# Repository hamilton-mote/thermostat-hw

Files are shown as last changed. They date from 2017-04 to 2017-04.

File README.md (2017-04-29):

# Hamilton open-source thermostat

The Hamilton thermostat is an open-source single stage thermostat built around the [Hamilton](https://github.com/hamilton-mote/hw) and [Nucleum](https://github.com/lab11/nucleum) motes. The core motivation of the project is to integrate the hardware necessary to turn these low-cost and low-power motes into an energy efficient and feature-rich thermostat.

The Hamilton thermostat can control a standard single stage heating and/or cooling system with a circular fan (R/Rh/Rc, W, Y, and G wires). The design features a temperature sensor (AT30TS74), humidity/temperature sensor (HDC1080), PIR sensor (EKMB1101111), real-time clock (MCP7940N), and 1Mbit EEPROM (AT24CM01). Wireless communication is achieved via the 802.15.4 radio (built into the SAMR21 of the Hamilton mote) or the Bluetooth Low Energy (BLE) radio (built into the NRF51822 of the Nucleum mote). The thermostat can be powered by 3 AA batteries or by 24VAC power (requires a C wire). The design also includes a simple user interface with 4 buttons and LED-based temperature and setting indication. The user interface can easily be replaced with a custom board by connecting to the main thermostat board via pinouts for the I2C bus, power (+3V3/GND), 2 analog pins, and 4 digital pins.

### Parts Overview

* AT30TS74 (I2C Address 1001000): The AT30TS74 temperature sensor has a configurable resolution of 9 to 12 bits and a typical accuracy of +/- 1 degree Celsius.
* HDC1080 (I2C Address 1000000): The HDC1080 humidity and temperature sensor has a configurable resolution of 8, 11, or 14 bits for humidity and 11 or 14 bit for temperature. The typical accuracy for humidity and temperature is +/- 2% and +/- 0.2 degree Celsius, respectively.
* MCP7940N (I2C Address 1101111): The MCP7940N is a real-time clock/calendar with SRAM.
* AT24CM02 (I2C Address 10100###): The AT24CM02 provides 2-Mbits (256-Kbytes) of Serial EEPROM. (Note: The original version of the Hamilton thermostat included AT24CM01 chips)
* PCA9557 (I2C Address 0011000): The PCA9557 is an 8 channel I/O parallel port expander. The expander is used to control the 3 latching relays (EE2-3TNUH-L) which actuate the heating system, cooling system, and circular fan.
* TLC59116 (I2C Addresses 1100001, 1100011, and 1100111): The TLC59116 is a 16 channel constant-current LED sink driver with 256-step (8-bit) linear programmable brightness. The Hamilton thermostat interface board includes 3 TLC59116 chips.
* EKMB1101111: The EKMB1101111 is a fully integrated PIR motion sensor with 1µA low current consumption. The output of the PIR sensor is connected to pin PA06 of the SAMR21 chip and P05/AIN6 of the NRF51822 chip.

### Communication

Communication between the SAMR21 chip or the NRF51822 chip and the other components of the Hamilton thermostat is primarily achieved via the shared I2C bus. The SAMR21 chip is connected to the bus with pin PA16 as SDA and PA17 as SCL and the NRF51822 chip is connected with pin P07 as SDA and P01 as SCL. The I2C addresses of the components are noted in the list above.

Communication between the SAMR21 chip and the NRF51822 chip is achieved over an SPI link. The SAMR21 chip is design to use SERCOM2 with PA08/PAD[0] as MOSI, PA09/PAD[1] as MISO,
PA15/PAD[3] as SCK, and PA14/PAD[2] as chip select.  The NRF51822 chip provides flexibility in the assignment of SPI pins and is designed to use P30 as MOSI, P29 as MISO, P00 as SCK, and P28 as chip select.

Additionally, the SAMR21 and NRF51822 chips are connected by several additional traces.
* A6 (the PIR sensor output) to SAMR21 pin PA06 and NRF51822 pin P05/AIN6.
* A7 to SAMR21 pin PA07 and NRF51822 pin P06/AIN7.
* D18 to SAMR21 pin PA18 and NRF51822 pin P18.
* D19 to SAMR21 pin PA19 and NRF51822 pin P19. There is also an LED connected to D19.
* D24 to SAMR21 pin PA24 and NRF51822 pin P25.
* D25 to SAMR21 pin PA25 and NRF51822 pin P25.
If necessary, these traces can be physically cut on the bottom on the Hamilton thermostat main board to sever the connections to the NRF51822 chip.

Lastly, the Hamilton thermostat is capable of wireless communication via the 802.15.4 radio (built into the SAMR21 chip) and the BLE radio (built into the NRF51822 chip).

### Relays

The Hamilton thermostat main board includes 3 EE2-3TNUH-L dual-coil latching signal relays for actuating a heating system (W wire), cooling system (Y wire), and circular fan (G wire).  Each relay is rated for a coil voltage of 3VDC, a contact current of 2A, and a switching voltage of up to 250VAC. Because the EE2-3TNUH-L is a latching relay, it maintains the contact position indefinitely without requiring a current to be applied. Thus, each relay contains 2 coils (1 for setting and 1 for releasing) and a current pulse is applied to either coil to change the contact position. Note that applying a current to one of the coils over a long period of time will damage the relay.

Each relay is connected to either the W wire (heat), Y wire (cooling), or G wire (fan). Setting a relay will connect the respective wire to the R/Rh/Rc wire and releasing the relay will sever the connection. The relays are controlled via the PCA9557 8 channel I/O expander. The W relay is connected to IO0 for setting and IO1 for releasing, the Y relay to IO2 for setting and IO3 for releasing, and the G relay to IO4 for setting and IO5 for releasing.

Lastly, the Hamilton thermostat is capable of simultaneously connecting the G wire (fan) when the W relay or Y relay is set. Adding the R18 jumper will cause the W relay to connect both the W and G wires to R when the relay is set and adding the R17 jumper will cause the Y relay to connect the Y and G relays to R.

### Power

The Hamilton thermostat can be power by battery and/or 24VAC power (if a C wire is available). The Hamilton thermostat main board includes a 3 AA battery holder and a AP2210 3.3VDC 300mA LDO regulator. If necessary, regulator can be bypassed by adding the R1 jumper.

If a C wire is available, the thermostat can operate on 24VAC power. For AC/DC conversion, the main board includes a full wave bridge rectifier and an OKI-78SR 36VDC to 3.3VDC 1.5A buck converter. The thermostat is designed to allow for operation on 24VAC power with battery backup.

### User Interface

The Hamilton thermostat has a simple and intuitive user interface for communicating the current temperature measurement and set point and for enabling a user to perform basic operations like setting the mode (heating, cooling, off) and adjusting the set point. The interface board includes four buttons: one for setting the mode, two for adjusting the temperature set point, and one for setting a temporary temperature hold.

The board also includes 40 LEDs for denoting the thermostats settings. To communicate the current temperature measurement and set point, 32 of the LEDs are arranged in an arc around the center of the board (16 for the measurement and 16 for the set point). The LEDs are controlled via three TLC59116 16 channel LED sink drivers.

The interface board is connected to the main thermostat board via pinouts for the I2C bus (SDA and SCL), power (+3.3VDC and GND), analog pins A6 and A7, and digital pins D18, D19, D24, and D25.

### Transient Voltage Suppression (TVS)

To protect the thermostat components from voltage spikes and electrostatic discharge (ESD), the Hamilton thermostat main and interface boards include several transient-voltage-suppression diodes.

On the main board:
* Diode D2 protects the 24VDC output of the diode rectifier and the voltage input of the buck converter.
* Diode D15 protects the batteries and the voltage input of the LDO regulator.
* Diode D16 protects the 3.3V line.
* Integrated diodes U8 (IP4220CZ6) protects the I2C lines.

On the interface board:
* Diodes D41, D42, D43, and D44 protect the output of each button on the interface board.
* Diode D45 protects the 3.3V line.
* Integrated diodes U5 (IP4220CZ6) protects the I2C lines.

### Changelog
* Added IP4220CZ6 diode (U8) to BOM of main board
* Replaced AT24CM01 with AT24CM02 in BOM of main board

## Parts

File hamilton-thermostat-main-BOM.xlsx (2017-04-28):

Name(s) | Part | Digikey Part | Description | Package | Price @ 5000 | Price @ 1 | Quantity Per | Links
A1 | 2450AT18A100E | 712-1005-1-ND | antenna |  | 0.2175 | 0.62 | 1 | http://www.digikey.com/product-detail/en/2450AT18A100E/712-1005-1-ND/1560834
A2 | FRACTUS-2.4GHZ-FR05-S1-N-0-102 |  | Fractus Compact Reach XtendTM chip antenna |  | 1.11 | 1.11 | 1 | http://www.richardsonrfpd.com/Pages/Product-Details.aspx?productId=921206
K1_W, K2_Y, K3_G | EE2-3TNUH-L | 399-11010-2-ND | Dual Coil Latching Relay (2A, 3V Coil) | DPDT (2 Form C) | 1.638 | 2.75 | 3 | http://www.digikey.com/product-detail/en/kemet/EE2-3TNUH-L/399-11010-2-ND/4291076 | http://www.digikey.com/products/en/relays/signal-relays-up-to-2-amps/189?k=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
D1 | SML-D12V1WT86 | SML-D12V1WT86CT-ND | led | 0603 (1608 Metric) | 0.03565 | 0.22 | 1 | http://www.digikey.com/product-detail/en/rohm-semiconductor/SML-D12V1WT86/SML-D12V1WT86CT-ND/5843857
D3, D4, D5, D6, D7, D8 | GS1A-LTP | GS1A-LTPMSCT-ND | Diode | DO-214AC | 0.04 | 0.28 | 6 | http://www.digikey.com/product-detail/en/micro-commercial-co/GS1A-LTP/GS1A-LTPMSCT-ND/3191613 | http://www.digikey.com/product-search/en?keywords=Micro%20Commercial%20Co%20GS1A-LTP
D9, D10, D11, D12, D13, D14 | SS2150-LTP | SS2150-LTPMSTR-ND | Schottky Diode (60V 2A) | DO-214AC | 0.0884 | 0.43 | 4 |  | http://www.digikey.com/products/en/discrete-semiconductor-products/diodes-rectifiers-single/280?k=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
D2 | SDC36C.TCT | SDC36CTCTTR-ND | 33V TVS Diode | SOT-23-3 | 0.66473 | 1.59 | 1 | http://www.digikey.com/product-detail/en/semtech-corporation/SDC36C.TCT/SDC36CTCTTR-ND/4626658
D15 | SMAJ11A | SMAJ11ALFTR-ND | 11V TVS Diode | DO-214AC, SMA | 0.10098 | 0.4 | 1 | http://www.digikey.com/product-detail/en/littelfuse-inc/SMAJ11A/SMAJ11ALFTR-ND/762268
D16 | MSP3V3-M3/89A | MSP3V3-M3/89AGITR-ND | 3V3 TVS Diode | MicroSMP | 0.0667 | 0.39 | 1 | http://www.digikey.com/product-detail/en/stmicroelectronics/SM2T3V3A/497-7878-2-ND/1039060
Q1, Q2, Q3, Q4, Q5, Q6 | MMBT2222ALT1G | MMBT2222ALT1GOSCT-ND | NPN Transistor | TO-236-3 | 0.01747 | 0.1 | 6 | http://www.digikey.com/product-detail/en/on-semiconductor/MMBT2222ALT1G/MMBT2222ALT1GOSCT-ND/1139806 | http://www.digikey.com/product-search/en?keywords=MMBT2222a
U1 | ATSAMR21E18A-MU or ATSAMR21E19A-MFTCT-ND | ATSAMR21E18A-MUTCT-ND | MCU | 32-VFQFN Exposed Pad | 4.236 | 4.64 | 1 | http://www.digikey.com/product-detail/en/ATSAMR21E18A-MU/ATSAMR21E18A-MU-ND/5016109
U2 | AT30TS74 | AT30TS74-U1FMAB-TTR-ND | Temp sensor | 5-WFBGA, WLCSP | 0.54075 | 0.68 | 1 | http://www.digikey.com/product-detail/en/microchip-technology/AT30TS74-U1FMAB-T/AT30TS74-U1FMAB-TTR-ND/6592985
U3 | HDC1080DMBR | 296-43864-2-ND | Temp sensor |  | 1.35 | 4.65 | 1 | http://www.digikey.com/product-detail/en/texas-instruments/HDC1080DMBT/296-43864-2-ND/5864876
U4 | MCP7940N | MCP7940N-I/SN-ND | I2C RTC | 8-SOIC | 0.6695 | 0.76 | 1 | http://www.digikey.com/product-detail/en/microchip-technology/MCP7940N-I-SN/MCP7940N-I-SN-ND/2651354
U5 | AT24CM02 | AT24CM02-SSHD-B-ND | 2Mbit EEPROM | 8-SOIC | 1.41831 | 2.2 | 1 | https://www.digikey.com/product-detail/en/microchip-technology/AT24CM02-SSHD-B/AT24CM02-SSHD-B-ND/5313448
U6 | AP2210N-3.3TRG1 | AP2210N-3.3TRG1DITR-ND | IC REG LDO 3.3V 0.3A SOT23 | SOT-23-3 | 0.09072 | 0.42 | 1 | http://www.digikey.com/product-detail/en/diodes-incorporated/AP2210N-3.3TRG1/AP2210N-3.3TRG1DITR-ND/4470822
U8 | IP4220CZ6,125 | 1727-3578-1-ND | ESD PROTECTION | SC-74, SOT-457 | 0.12128 | 0.44 | 1 | https://www.digikey.com/product-detail/en/nexperia-usa-inc/IP4220CZ6,125/1727-3578-1-ND/1133548
U10 | NRF51822QF | 1490-1040-1-ND | BLE/2.4 GHz RF SoC | 48-VFQFN Exposed Pad | 2.7048 | 5.41 | 1 | http://www.digikey.com/products/en?keywords=1490-1040-1-ND
U11 | PCA9557BS,118 | 568-3398-1-ND | I/O EXPANDER I2C 8B | 16-HVQFN | 0.63963 | 1.41 | 1 | http://www.digikey.com/product-detail/en/nxp-usa-inc/PCA9557BS,118/568-3398-1-ND/1125743 | http://www.digikey.com/products/en?keywords=pca9557bs
X1 | 7S-16.000MAHE-T | 887-1833-1-ND | xtal | 4-SMD | 0.5075 | 1 | 1 | http://www.digikey.com/product-search/en?keywords=887-1833-1-ND
X2 | TXC-8Y | 887-2003-1-ND | CRYSTAL 16MHZ 8PF SMD | 4-SMD | 0.495 | 0.86 | 1 | http://www.digikey.com/products/en?keywords=887-2003-1-ND
X3 | ABS05-32.768KHZ-T | 535-11899-1-ND | 32.768kHz Crystal | 2-SMD | 0.64515 | 1.12 | 1 | http://www.digikey.com/products/en?keywords=535-11899-1-ND
X4 | ABS05-32.768KHZ-9-T | 535-11897-2-ND | 32.768kHz Crystal (9 pF) | 2-SMD | 0.56695 | 1.12 | 1 | http://www.digikey.com/product-detail/en/abracon-llc/ABS05-32.768KHZ-9-T/535-11897-2-ND/3508064
L1 | 2450BM15A0015E | 712-1576-1-ND | balun | 0805 (2012 Metric) | 0.41345 | 0.96 | 1 | http://www.digikey.com/product-detail/en/2450BM15A0015E/712-1576-1-ND/4770709
L2 | INDUCTOR0402 | 587-1521-1-ND | 15nH 0402_IND | 0402 (1005 Metric) | 0.02285 | 0.1 | 1 | http://www.digikey.com/products/en?keywords=587-1521-1-ND
L3 | INDUCTOR0603 | 490-4025-1-ND | 10uH 0603_IND | 0603 (1608 Metric) | 0.06734 | 0.14 | 1 | http://www.digikey.com/products/en?keywords=490-4025-1-ND
L4 | BAL-NRF01D3 | 497-13637-1-ND | 50 ohm nominal match balun to nRF51422-QFAA, | 5-WFBGA, FCBGA | 0.3296 | 0.77 | 1 | http://www.digikey.com/products/en?keywords=497-13637-1-ND
C16, C17, C20, C21 | 0402 Capacitor | 399-1013-2-ND | 12pF 0402_CAP | 0402 (1005 Metric) | 0.00615 | 0.1 | 4 | http://www.digikey.com/product-detail/en/kemet/C0402C120J5GACTU/399-1013-2-ND/411015
C18 | 0402 Capacitor | 445-8093-2-ND | 47nF 0402_CAP | 0402 (1005 Metric) | 0.02545 | 0.18 | 1 | http://www.digikey.com/product-detail/en/tdk-corporation/CGJ2B2X7R1C473K050BA/445-8093-2-ND/2812479
C22 | 0402 Capacitor | 399-13404-2-ND | 2.2nF 0402_CAP | 0402 (1005 Metric) | 0.02182 | 0.16 | 1 | http://www.digikey.com/product-detail/en/kemet/C0402C222J8JAC7867/399-13404-2-ND/6123085
C23 | 0402 Capacitor | 1284-1093-2-ND | 0.8pF 0402_CAP | 0402 (1005 Metric) | 0.40365 | 1.27 | 1 | http://www.digikey.com/products/en?keywords=1284-1093-2-ND
C26 | 0402 Capacitor | 490-5915-2-ND | 4.7uF 0402_CAP | 0402 (1005 Metric) | 0.01919 | 0.14 | 1 | http://www.digikey.com/product-detail/en/murata-electronics-north-america/GRM155R60J475ME47D/490-5915-2-ND/3694656
C28, C29 | GRM1555C1H9R0CA01D | 490-8232-2-ND | 9pF 0402_CAP | 0402 (1005 Metric) | 0.00615 | 0.1 | 2 | http://www.digikey.com/product-detail/en/murata-electronics-north-america/GRM1555C1H9R0CA01D/490-8232-2-ND/3693892
C31 | UWT1H101MNL1GS | 493-2226-2-ND | 100 uF Alum Cap (50V) | Radial, Can | 0.11475 | 0.15 | 1 |  | http://www.digikey.com/product-detail/en/nichicon/UWT1H101MNL1GS/493-2226-2-ND/589967
C32 | UMK316BBJ106ML-T | 587-3248-1-ND | 10 uF Cer Cap (50V) | 1206 (3216 Metric) | 0.10659 | 0.12 | 1 |  | http://www.digikey.com/product-detail/en/taiyo-yuden/UMK316BBJ106ML-T/587-3248-2-ND/3660083
R15 | 0402 Resistor | RHM12.0KCDCT-ND | 12k 0402_RES | 0402 (1005 Metric) | 0.0034 | 0.1 | 1 | http://www.digikey.com/products/en?keywords=RHM12.0KCDCT-ND
U9 | OKI-78SR-3.3/1.5-W36-C | 811-2195-5-ND | DC/DC 4.95W 36VIN 3.3VOUT | 3-SIP Module | 4.3 | 3.60432 | 1 | http://www.digikey.com/product-detail/en/murata-power-solutions-inc/OKI-78SR-3.3-1.5-W36-C/811-2195-5-ND/2259780 | http://www.digikey.com/products/en/power-supplies-board-mount/dc-dc-converters/922?k=oki%2078s
J2 | 1935200 | 277-1581-ND | 6POS Screw Terminal | N/A | 0.8245 | 1.12 | 1 | http://www.digikey.com/product-detail/en/phoenix-contact/1935200/277-1581-ND/568618
BT2 (back of board) | Keystone Electronics 2464 | 36-2464-ND | Battery Holder 3 AA | N/A | 0.67431 | 2.02 | 1 | http://www.digikey.com/product-detail/en/keystone-electronics/2464/36-2464-ND/303813
Passives, any brand is ok:
C1, C2 | 20pF 0402 6v3 NP0 / C0G |  |  |  | 0.00339 | 0.1 | 2
C3, C7, C8, C9, C10, C11, C12, C25 | 100nF 0402 6v3 X5R |  |  |  | 0.00216 | 0.1 | 7
C4, C13, C14, C15, C30 | 10uF 0805 6v3 X5R |  |  |  | 0.00575 | 0.1 | 4
C5, C6, C27 | 1uF 0402 6v3 X5R |  |  |  | 0.00191 | 0.1 | 2
C19, C24 | 1nF 0402_CAP |  |  |  | 0.02917 | 0.19 | 2 | http://www.digikey.com/product-detail/en/kemet/C0402C102J5JAC7867/399-13381-2-ND/6123062
R2, R3, R4, R5, R6, R7, R8 | 1K 0402 5% |  |  |  | 0.00121 | 0.1 | 7
R9, R10, R11, R12, R13, R14 | 10k 0402 5% |  |  |  | 0.00121 | 0.1 | 6 | http://www.digikey.com/product-detail/en/yageo/RC0402JR-0710KL/311-10KJRCT-ND/729365 | http://www.digikey.com/product-search/en/resistors/chip-resistor-surface-mount/65769?k=10k+resistor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
R16, R19, R20 | 2k55 0402 5% |  |  |  | 0.00122 | 0.1 | 2 | http://www.digikey.com/product-detail/en/yageo/RC0402FR-072K55L/YAG3102TR-ND/5280962
Do not populate:
BT1 (back of board) | 6S-2-3A |  | Battery holder |  |  |  |  | http://www.digikey.com/product-detail/en/6S-2-3A/6S-2-3A-ND/2077834
U7 | EKMB1101111 |  | PIR |  |  |  |  | http://www.digikey.com/product-detail/en/panasonic-electric-works/EKMB1101111/255-3065-ND/2601859
R1, R17, R18 | 0R 0402 (jumper)

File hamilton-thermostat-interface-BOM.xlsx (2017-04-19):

Name(s) | Part | Digikey Part | Description | Package | Price @ 5000 | Price @ 1 | Quantity Per | Links
U1, U2, U3 | TLC59116 | 296-23354-1-ND | LED Driver IC 16 Output Linear I²C Dimming | 28-TSSOP | 1.125 | 2.73 | 3 | https://www.digikey.com/product-detail/en/texas-instruments/TLC59116IPWR/296-23354-1-ND/1835679
U4 | EKMB1101111 | 255-3065-ND | PIR |  | 19.404 | 30.49 | 1 | http://www.digikey.com/product-detail/en/panasonic-electric-works/EKMB1101111/255-3065-ND/2601859
U5 | IP4220CZ6,125 | 1727-3578-1-ND | ESD PROTECTION | SC-74, SOT-457 | 0.12128 | 0.44 | 1 | https://www.digikey.com/product-detail/en/nexperia-usa-inc/IP4220CZ6,125/1727-3578-1-ND/1133548
J1, J2, J3, J4 | PTS645SK50SMTR92 LFS | CKN9087TR-ND | SWITCH TACTILE SPST-NO 0.05A 12V |  | 0.10875 | 0.25 | 4 | https://www.digikey.com/product-detail/en/c-k/PTS645SK50SMTR92-LFS/CKN9087TR-ND/1162183
D1, D2, D3, D4, D5, D6, D7, D8, D9, D10, D11, D12, D13, D14, D15, D16, D37, D38, D39, D40 | LP L296-J2L2-25-Z | 475-2920-1-ND | Green LED | 0603 (1608 Metric) | 0.0962 | 0.48 | 20 | https://www.digikey.com/product-detail/en/osram-opto-semiconductors-inc/LP-L296-J2L2-25-Z/475-2920-1-ND/2424965
D17, D18, D19, D20, D21, D22, D23, D24, D25, D26, D27, D28, D29, D30, D31, D32, D33, D34, D35, D36 | LA L296-Q2R2-1-Z | 475-2712-2-ND | Amber LED | 0603 (1608 Metric) | 0.0962 | 0.48 | 20 | https://www.digikey.com/product-detail/en/osram-opto-semiconductors-inc/LA-L296-Q2R2-1-Z/475-2712-2-ND/1938743
D41, D42, D43, D44, D45 | MSP3V3-M3/89A | MSP3V3-M3/89AGITR-ND | 3V3 TVS Diode | MicroSMP | 0.0667 | 0.39 | 5 | http://www.digikey.com/product-detail/en/stmicroelectronics/SM2T3V3A/497-7878-2-ND/1039060
R1, R4, R8 | RC0402FR-07931RL | YAG3259TR-ND | 931 Res 0402 | 0402 (1005 Metric) | 0.00122 | 0.1 | 3 | https://www.digikey.com/product-detail/en/yageo/RC0402FR-07931RL/YAG3259TR-ND/5281119
Passives, any brand is ok:
R2, R3, R5, R6, R7, R9, R10, R11, R12 | 1K 0402 5% |  |  |  | 0.00121 | 0.1 | 9
R13, R15, R17, R19 | 200 0402 5% |  |  |  | 0.00289 | 0.1 | 4
R14, R16, R18, R20 | 47K 0402 5% |  |  |  | 0.00204 | 0.1 | 4
C1, C2, C3, C4 | 1uF 0402 6v3 X5R |  |  |  | 0.00191 | 0.1 | 4

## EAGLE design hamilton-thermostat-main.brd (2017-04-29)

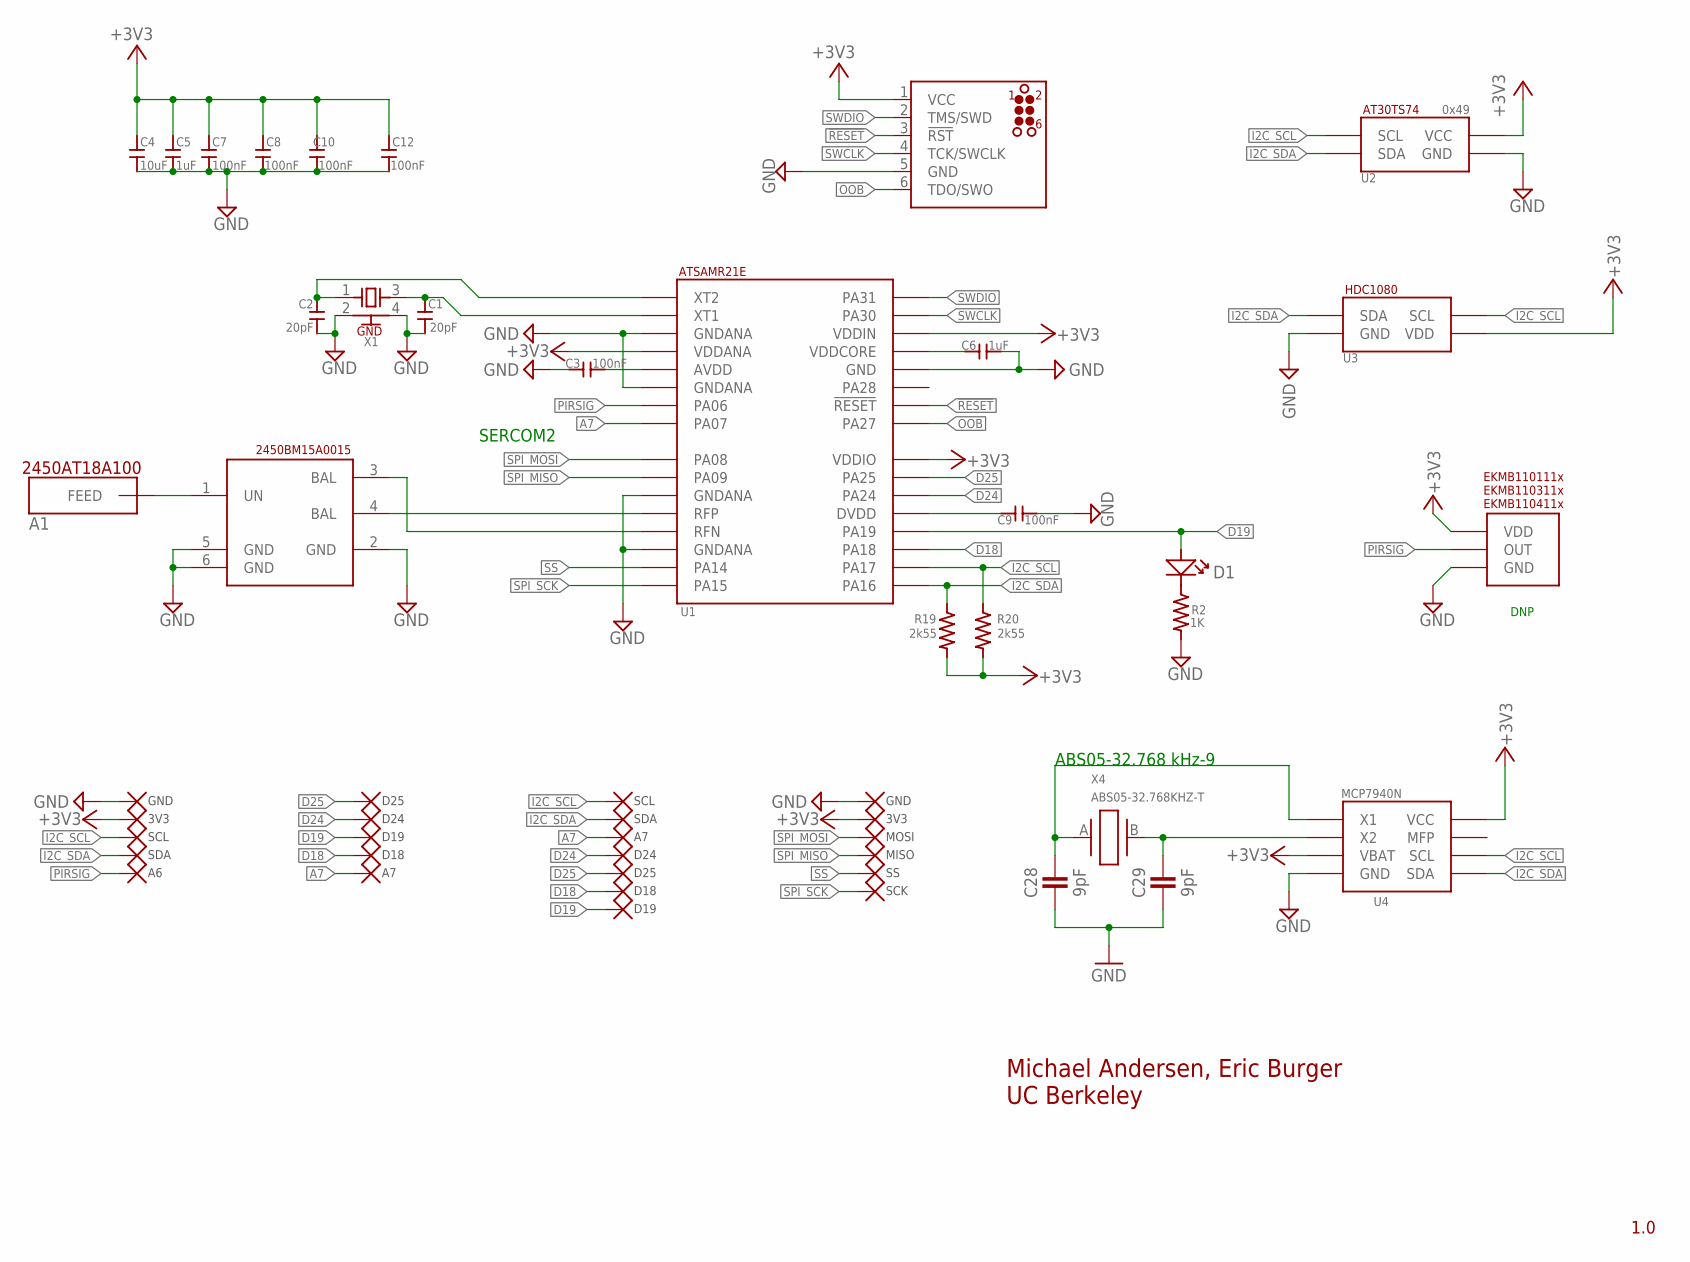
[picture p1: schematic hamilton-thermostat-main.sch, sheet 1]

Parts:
A1: JOHANSON_ANTENNA2
C1, C2: 20pF; S0402
C3, C7, C8, C9, C10, C12: 100nF; S0402
C4: 10uF; 0805
C5, C6: 1uF; S0402
C28, C29: 9pF; 0402_CAP
D1: DNP; LINE_0603
L1: BALUN_JOHANSON
R2: 1K; S0402
R19, R20: 2k55; S0402
TP1, TP18: D19; TPP
TP2, TP17: D18; TPP
TP3, TP19: A7; TPP
TP4, TP14: D25; TPP
TP6, TP12: GND; TPP
TP7, TP9: SDA; TPP
TP8, TP10: SCL; TPP
TP11, TP24: 3V3; TPP
TP13, TP15: D24; TPP
TP16: A6; TPP
TP20: MOSI; TPP
TP21: MISO; TPP
TP22: SS; TPP
TP23: SCK; TPP
U1: SAMR21; QFN32
U2: AT30TS74; 4WLCSP
U3: HDC1080; WSON_HDC1080
U4: MCP7940N; SO8
U7: PANASONIC_PIR; PIR
U$1: JLINK_CONNECTWL; TC2030-MCP
X1: XTAL
X4: ABS05-32.768KHZ-T; ABS05

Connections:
!RESET!: U1.26 (!RESET!), U$1.3 (!RST!)
+3V3: C4.2, C5.P$2, C7.P$1, C8.P$1, C10.P$1, C12.P$1, R19.P$1, R20.P$1, TP11.P$1, TP24.P$1, U1.4 (VDDANA), U1.24 (VDDIO), U1.30 (VDDIN), U2.A1 (VCC), U3.5 (VDD), U4.3 (VBAT), U4.8 (VCC), U7.VDD, U$1.1 (VCC); also elsewhere on the board
A7: TP3.P$1, TP19.P$1, U1.8 (PA07); also elsewhere on the board
D18: TP2.P$1, TP17.P$1, U1.19 (PA18); also elsewhere on the board
D19: D1.P (+), TP1.P$1, TP18.P$1, U1.20 (PA19); also elsewhere on the board
D24: TP13.P$1, TP15.P$1, U1.22 (PA24); also elsewhere on the board
D25: TP4.P$1, TP14.P$1, U1.23 (PA25); also elsewhere on the board
GND: C1.P$1, C2.P$1, C3.P$2, C4.1, C5.P$1, C6.P$1, C7.P$2, C8.P$2, C9.P$1, C10.P$2, C12.P$2, C28.2, C29.2, L1.2 (GND), L1.5 (GND), L1.6 (GND), R2.P$1, TP6.P$1, TP12.P$1, U1.3 (GNDANA), U1.6 (GNDANA), U1.11 (GNDANA), U1.14 (GNDANA), U1.28 (GND), U2.A2 (GND), U3.2 (GND), U4.4 (GND), U7.GND, U$1.5 (GND), X1.2 (GND), X1.4 (GND); also elsewhere on the board
I2C_SCL: R20.P$2, TP8.P$1, TP10.P$1, U1.18 (PA17), U2.B2 (SCL), U3.6 (SCL), U4.6 (SCL); also elsewhere on the board
I2C_SDA: R19.P$2, TP7.P$1, TP9.P$1, U1.17 (PA16), U2.B1 (SDA), U3.1 (SDA), U4.5 (SDA); also elsewhere on the board
unnamed: L1.3 (BAL), U1.13 (RFN)
unnamed: A1.FEED, L1.1 (UN)
unnamed: C2.P$2, U1.1 (XT2), X1.1 (X1)
unnamed: C6.P$2, U1.29 (VDDCORE)
unnamed: C3.P$1, U1.5 (AVDD)
unnamed: C1.P$2, U1.2 (XT1), X1.3 (X2)
unnamed: C9.P$2, U1.21 (DVDD)
unnamed: L1.4 (BAL), U1.12 (RFP)
unnamed: D1.N (-), R2.P$2
unnamed: C28.1, U4.1 (X1), X4.A (1)
unnamed: C29.1, U4.2 (X2), X4.B (2)
OOB: U1.25 (PA27), U$1.6 (TDO/SWO)
PIRSIG: TP16.P$1, U1.7 (PA06), U7.OUT; also elsewhere on the board
SPI_MISO: TP21.P$1, U1.10 (PA09); also elsewhere on the board
SPI_MOSI: TP20.P$1, U1.9 (PA08); also elsewhere on the board
SPI_SCK: TP23.P$1, U1.16 (PA15); also elsewhere on the board
SS: TP22.P$1, U1.15 (PA14); also elsewhere on the board
SWCLK: U1.31 (PA30), U$1.4 (TCK/SWCLK)
SWDIO: U1.32 (PA31), U$1.2 (TMS/SWD)

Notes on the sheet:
1.0
Michael Andersen, Eric Burger UC Berkeley
0x49
SERCOM2
ABS05-32.768 kHz-9
DNP

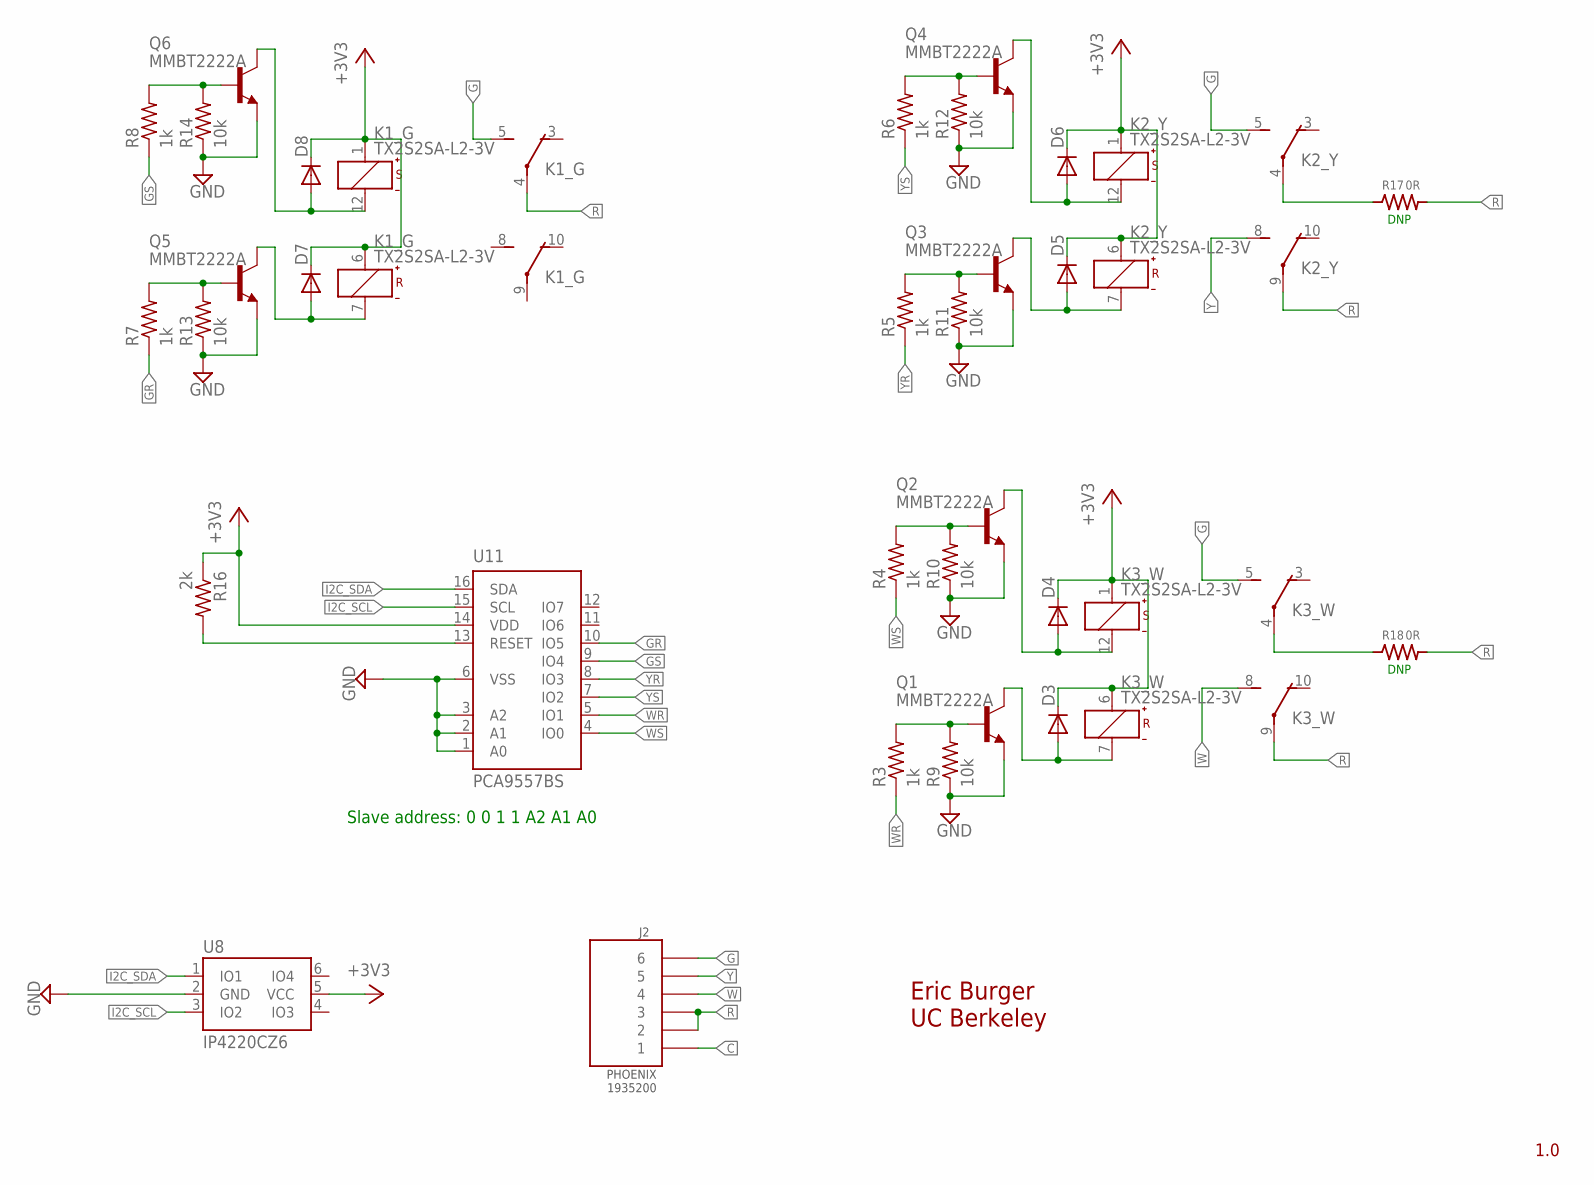
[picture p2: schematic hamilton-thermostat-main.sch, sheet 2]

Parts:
D3, D4, D5, D6, D7, D8: DIODE-DO-214AC; DO-214AC
J2: PHOENIX6W5MM
K1_G, K2_Y, K3_W: TX2S2SA-L2-3V; TX2SA-L2
Q1, Q2, Q3, Q4, Q5, Q6: MMBT2222A; SOT23-3
R3, R4, R5, R6, R7, R8: 1k; R0402
R9, R10, R11, R12, R13, R14: 10k; R0402
R16: 2k; R0402
R17, R18: 0R; S0402
U8: IP4220CZ6; SOT23-6
U11: PCA9557BS; HVQFN16_4X4

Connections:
+3V3: D3.C, D4.C, D5.C, D6.C, D7.C, D8.C, K1_G.1 (+), K1_G.6 (+), K2_Y.1 (+), K2_Y.6 (+), K3_W.1 (+), K3_W.6 (+), R16.1, U8.5 (VCC), U11.14 (VDD); also elsewhere on the board
C: J2.P$1 (1); also elsewhere on the board
G: J2.P$6 (6), K1_G.5 (S), K2_Y.5 (S), K3_W.5 (S)
GND: Q1.2 (E), Q2.2 (E), Q3.2 (E), Q4.2 (E), Q5.2 (E), Q6.2 (E), R9.1, R10.1, R11.1, R12.1, R13.1, R14.1, U8.2 (GND), U11.1 (A0), U11.2 (A1), U11.3 (A2), U11.6 (VSS); also elsewhere on the board
GR: R7.1, U11.10 (IO5)
GS: R8.1, U11.9 (IO4)
I2C_SCL: U8.3 (IO2), U11.15 (SCL); also elsewhere on the board
I2C_SDA: U8.1 (IO1), U11.16 (SDA); also elsewhere on the board
unnamed: Q2.1 (B), R4.2, R10.2
unnamed: R16.2, U11.13 (RESET)
unnamed: D3.A, K3_W.7 (-), Q1.3 (C)
unnamed: D4.A, K3_W.12 (-), Q2.3 (C)
unnamed: Q4.1 (B), R6.2, R12.2
unnamed: Q1.1 (B), R3.2, R9.2
unnamed: D5.A, K2_Y.7 (-), Q3.3 (C)
unnamed: Q3.1 (B), R5.2, R11.2
unnamed: D6.A, K2_Y.12 (-), Q4.3 (C)
unnamed: Q6.1 (B), R8.2, R14.2
unnamed: D7.A, K1_G.7 (-), Q5.3 (C)
unnamed: Q5.1 (B), R7.2, R13.2
unnamed: D8.A, K1_G.12 (-), Q6.3 (C)
unnamed: K2_Y.4, R17.P$2
unnamed: K3_W.4, R18.P$2
R: J2.P$2 (2), J2.P$3 (3), K1_G.4, K2_Y.9, K3_W.9, R17.P$1, R18.P$1; also elsewhere on the board
W: J2.P$4 (4), K3_W.8 (S)
WR: R3.1, U11.5 (IO1)
WS: R4.1, U11.4 (IO0)
Y: J2.P$5 (5), K2_Y.8 (S)
YR: R5.1, U11.8 (IO3)
YS: R6.1, U11.7 (IO2)

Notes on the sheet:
1.0
Eric Burger UC Berkeley
Slave address: 0 0 1 1 A2 A1 A0
DNP

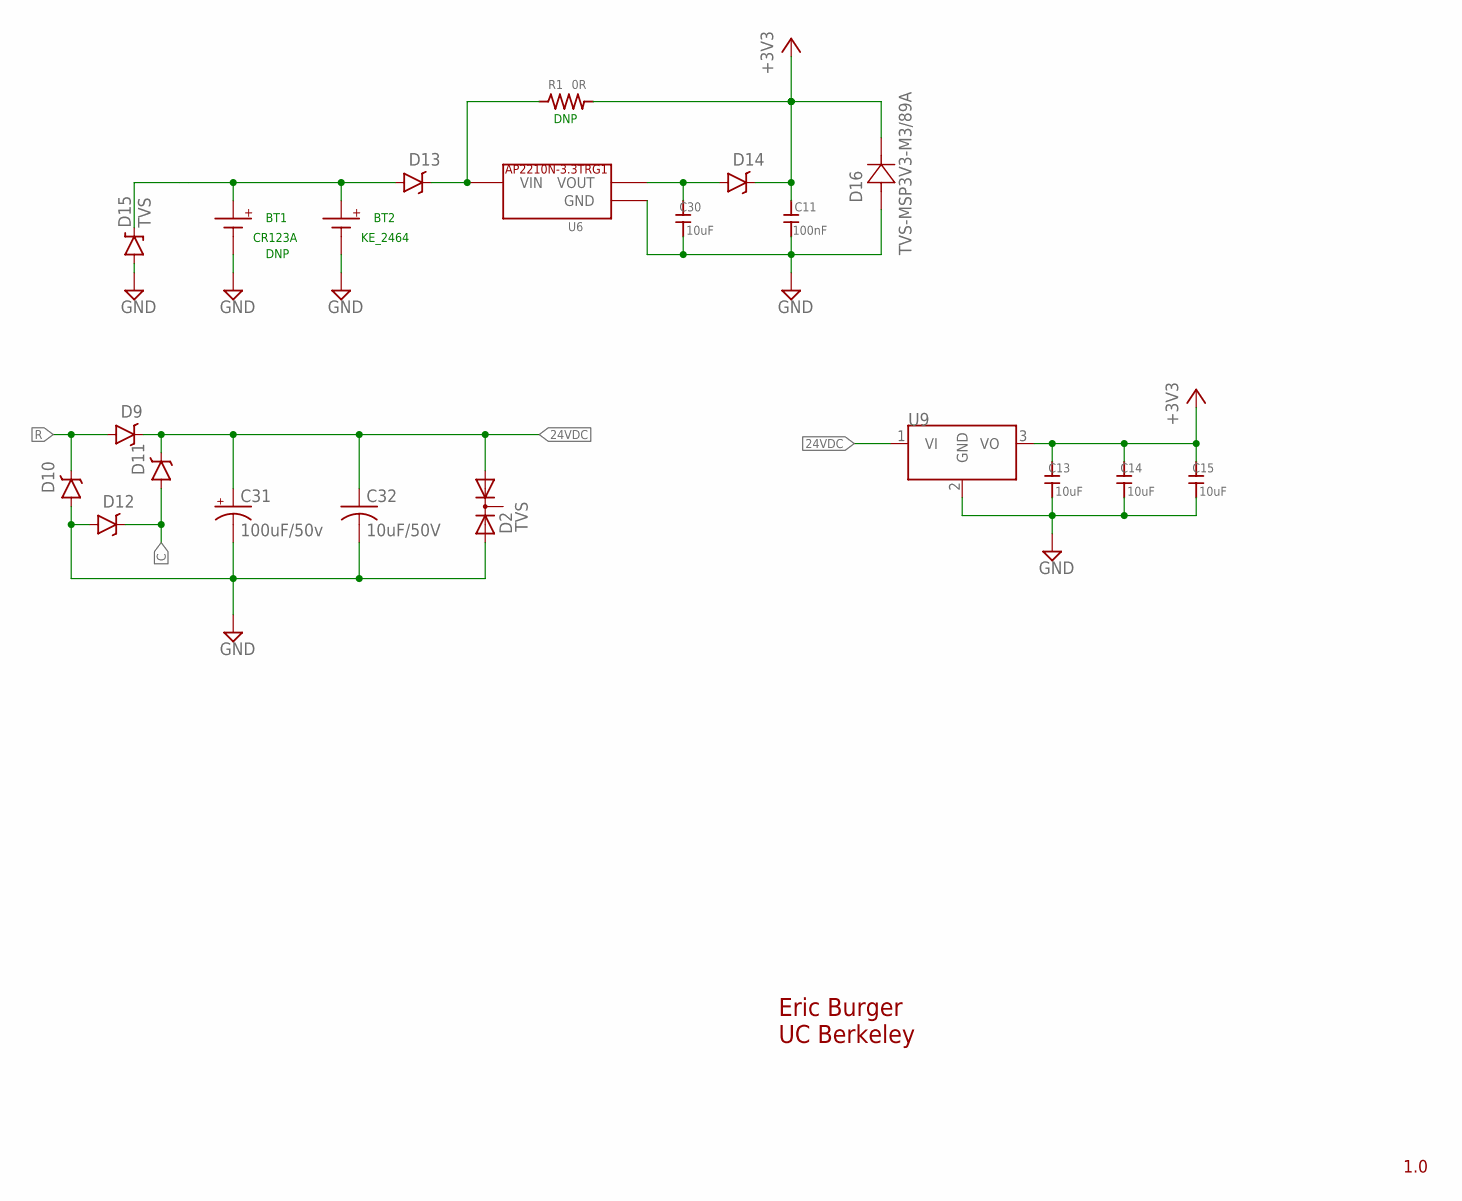
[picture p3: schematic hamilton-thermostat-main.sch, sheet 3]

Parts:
BT1: CR123A
BT2: BATTERY; KE_2464
C11: 100nF; S0402
C13, C14, C15, C30: 10uF; 0805
C31: 100uF/50v; NIC_10X10.5_CAP
C32: 10uF/50V; C1206
D2: TVS; SOT23
D9, D10, D11, D12, D13, D14: MBRA140; SMA-DIODE
D15: TVS; SMB-DIODE
D16: TVS-MSP3V3-M3/89A; DIODE_MSP3V3
R1: 0R; S0402
U6: SOT23-3VREG; SOT23
U9: DCDC_OKI-78SR; OKI-78SRH

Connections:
24VDC: C31.+, C32.1, D2.1 (A1), D9.C, D11.C, U9.1 (VI)
+3V3: C11.P$1, C13.2, C14.2, C15.2, D14.C, D16.1 (12), R1.P$1, U9.3 (VO); also elsewhere on the board
C: D11.A, D12.C; also elsewhere on the board
GND: BT1.NEG (-), BT2.NEG (-), C11.P$2, C13.1, C14.1, C15.1, C30.1, C31.-, C32.2, D2.2 (A2), D10.A, D12.A, D15.A, D16.2 (21), U6.1 (GND), U9.2 (GND); also elsewhere on the board
unnamed: C30.2, D14.A, U6.2 (VOUT)
unnamed: D13.C, R1.P$2, U6.3 (VIN)
unnamed: BT1.POS (+), BT2.POS (+), D13.A, D15.C
R: D9.A, D10.C; also elsewhere on the board

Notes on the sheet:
1.0
Eric Burger UC Berkeley
CR123A
DNP
KE_2464
BT1
BT2

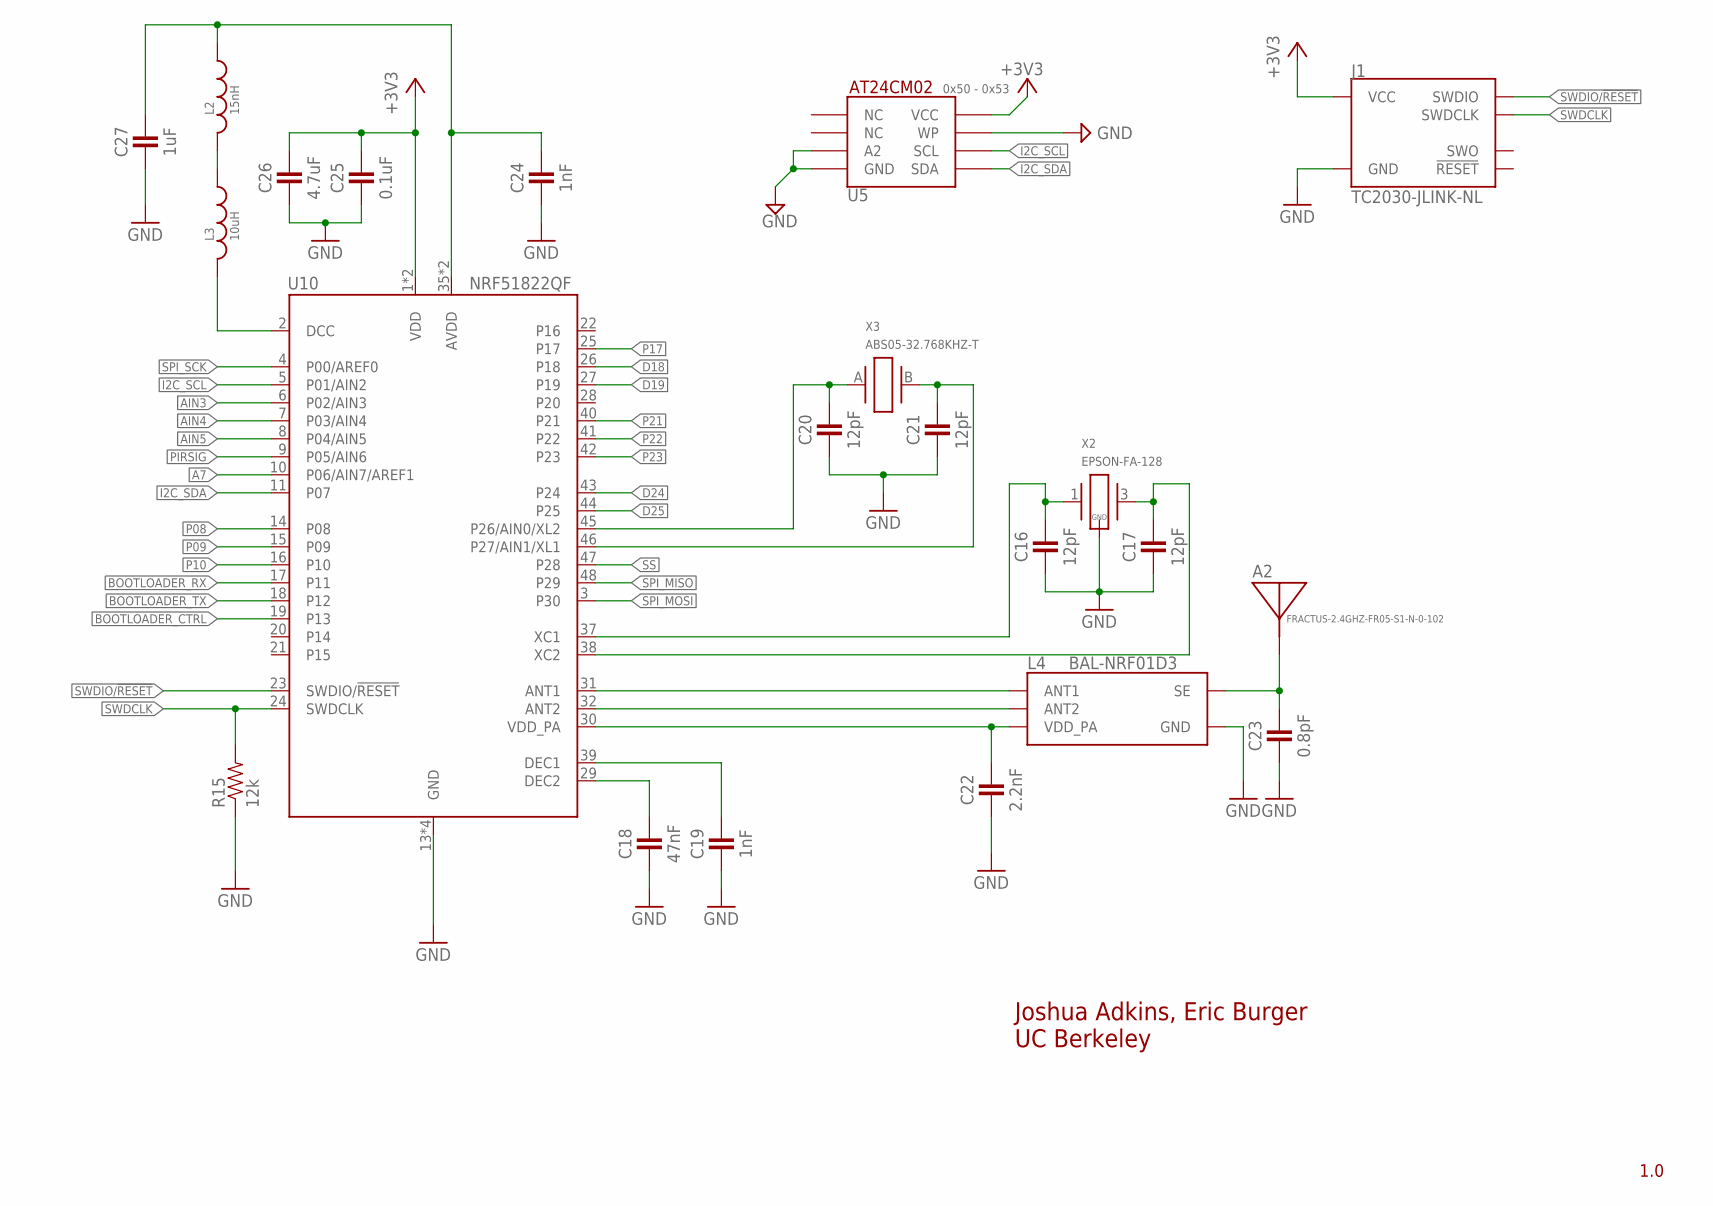
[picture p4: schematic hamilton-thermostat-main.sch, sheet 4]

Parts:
A2: FRACTUS-2.4GHZ-FR05-S1-N-0-102; FRACTUS-ANTENNA-FR05-S1-N-0-102
C16, C17, C20, C21: 12pF; 0402_CAP
C18: 47nF; 0402_CAP
C19, C24: 1nF; 0402_CAP
C22: 2.2nF; 0402_CAP
C23: 0.8pF; 0402_CAP
C25: 0.1uF; 0402_CAP
C26: 4.7uF; 0402_CAP
C27: 1uF; 0402_CAP
J1: TC2030-JLINK-NL; TC2030-IDC-NL
L2: 15nH; 0402_CAP
L3: 10uH; 0603_CAP
L4: BAL-NRF01D3
R15: 12k; 0402_RES
U5: AT24CM02; SO8
U10: NRF51822QF; QFN-48-6MM
X2: EPSON-FA-128; FA-128
X3: ABS05-32.768KHZ-T; ABS05

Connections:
+3V3: C25.1, C26.1, J1.1 (VCC), U5.8 (VCC), U10.1 (VDD), U10.12 (VDD); also elsewhere on the board
A7: U10.10 (P06/AIN7/AREF1); also elsewhere on the board
AIN3: U10.6 (P02/AIN3)
AIN4: U10.7 (P03/AIN4)
AIN5: U10.8 (P04/AIN5)
ANTENNA: A2.1, C23.1, L4.SE
BOOTLOADER_CTRL: U10.19 (P13)
BOOTLOADER_RX: U10.17 (P11)
BOOTLOADER_TX: U10.18 (P12)
D18: U10.26 (P18); also elsewhere on the board
D19: U10.27 (P19); also elsewhere on the board
D24: U10.43 (P24); also elsewhere on the board
D25: U10.44 (P25); also elsewhere on the board
GND: C16.2, C17.2, C18.2, C19.2, C20.2, C21.2, C22.2, C23.2, C24.2, C25.2, C26.2, C27.2, J1.5 (GND), L4.GND, R15.1, U5.3 (A2), U5.4 (GND), U5.7 (WP), U10.13 (GND), U10.33 (GND), U10.34 (GND), U10.GND, X2.2 (GND), X2.4 (GND); also elsewhere on the board
I2C_SCL: U5.6 (SCL), U10.5 (P01/AIN2); also elsewhere on the board
I2C_SDA: U5.5 (SDA), U10.11 (P07); also elsewhere on the board
unnamed: C16.1, U10.37 (XC1), X2.1
unnamed: C17.1, U10.38 (XC2), X2.3 (2)
unnamed: C18.1, U10.29 (DEC2)
unnamed: C20.1, U10.45 (P26/AIN0/XL2), X3.A (1)
unnamed: C21.1, U10.46 (P27/AIN1/XL1), X3.B (2)
unnamed: C19.1, U10.39 (DEC1)
unnamed: L4.ANT1, U10.31 (ANT1)
unnamed: L4.ANT2, U10.32 (ANT2)
unnamed: C22.1, L4.VCC (VDD_PA), U10.30 (VDD_PA)
unnamed: C24.1, C27.1, L2.1, U10.35 (AVDD), U10.36 (AVDD)
unnamed: L2.2, L3.1
unnamed: L3.2, U10.2 (DCC)
P08: U10.14 (P08)
P09: U10.15 (P09)
P10: U10.16 (P10)
P17: U10.25 (P17)
P21: U10.40 (P21)
P22: U10.41 (P22)
P23: U10.42 (P23)
PIRSIG: U10.9 (P05/AIN6); also elsewhere on the board
SPI_MISO: U10.48 (P29); also elsewhere on the board
SPI_MOSI: U10.3 (P30); also elsewhere on the board
SPI_SCK: U10.4 (P00/AREF0); also elsewhere on the board
SS: U10.47 (P28); also elsewhere on the board
SWDCLK: J1.4 (SWDCLK), R15.2, U10.24 (SWDCLK)
SWDIO/!RESET: J1.2 (SWDIO), U10.23 (SWDIO/!RESET)

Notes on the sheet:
Joshua Adkins, Eric Burger UC Berkeley
1.0
0x50 - 0x53

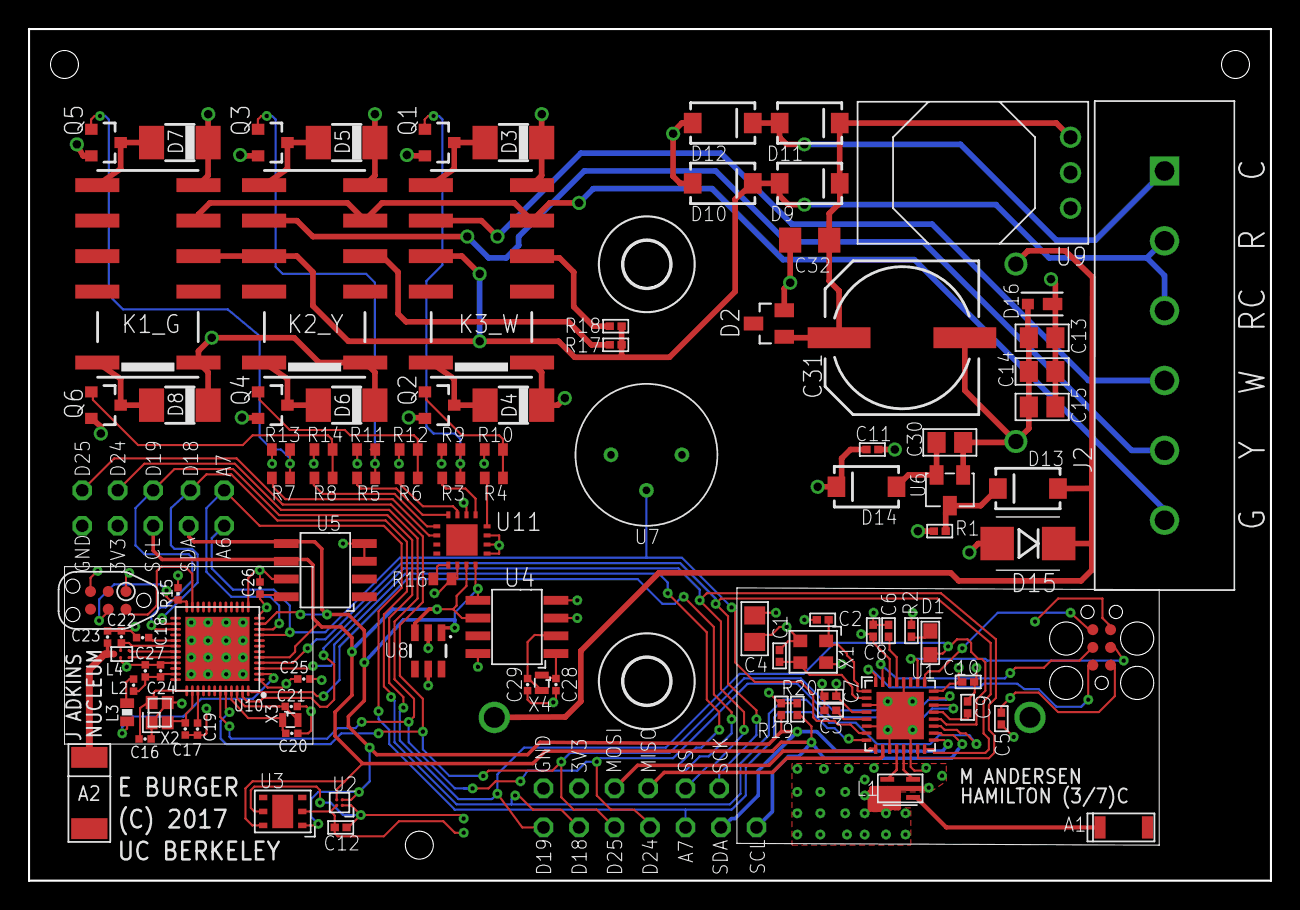
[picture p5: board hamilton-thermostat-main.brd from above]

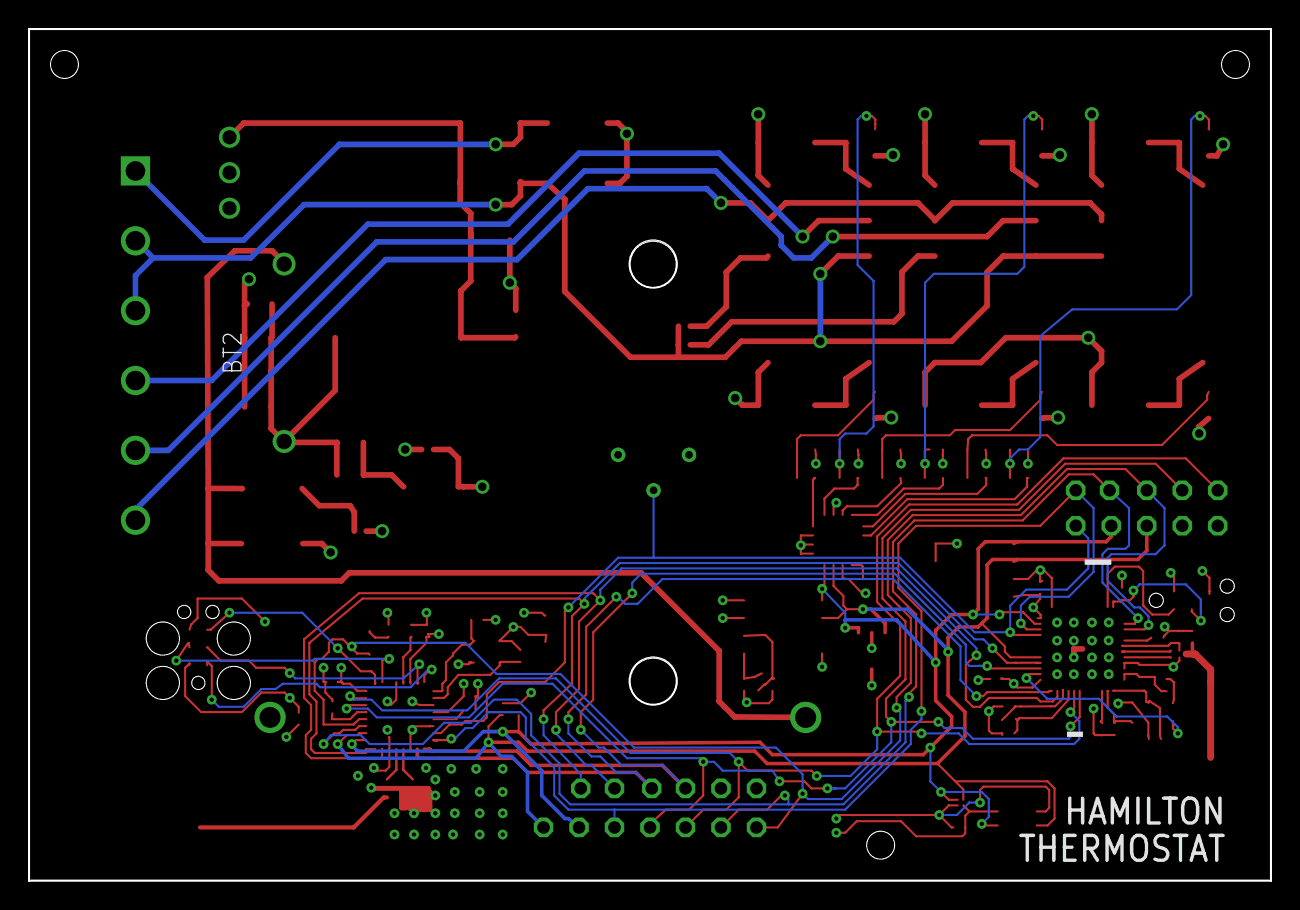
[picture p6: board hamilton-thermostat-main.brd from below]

Board: 4 copper layers, 88.9 x 61.0 mm, 128 parts (2 on the bottom side), 74 nets.

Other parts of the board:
U$3, U$4: 3,3

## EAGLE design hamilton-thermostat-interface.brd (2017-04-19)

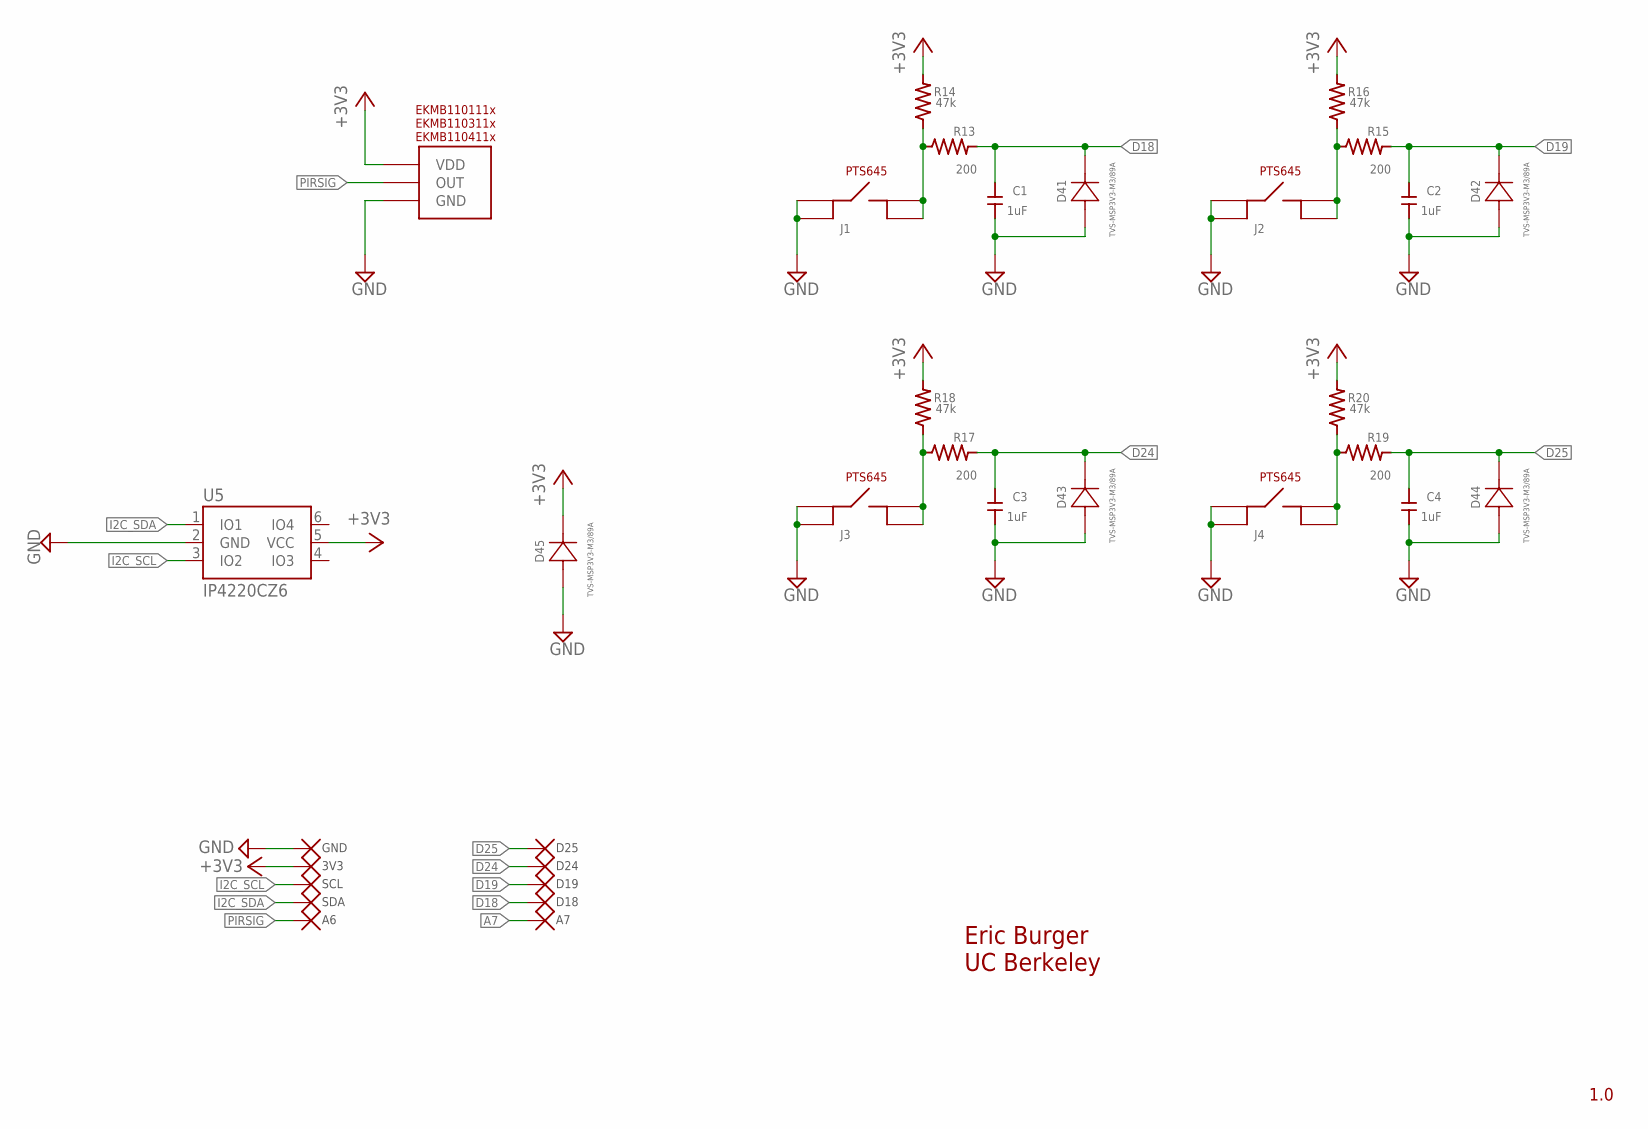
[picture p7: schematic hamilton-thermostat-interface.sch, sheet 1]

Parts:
C1, C2, C3, C4: 1uF; S0402
D41, D42, D43, D44, D45: TVS-MSP3V3-M3/89A; DIODE_MSP3V3
J1, J2, J3, J4: PTS645
R13, R15, R17, R19: 200; S0402
R14, R16, R18, R20: 47k; S0402
TP9: SDA; TPP
TP10: SCL; TPP
TP11: 3V3; TPP
TP12: GND; TPP
TP14: D25; TPP
TP15: D24; TPP
TP16: A6; TPP
TP17: D18; TPP
TP18: D19; TPP
TP19: A7; TPP
U4: PANASONIC_PIR; PIR
U5: IP4220CZ6; SOT23-6

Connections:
+3V3: D45.1 (12), R14.P$1, R16.P$1, R18.P$1, R20.P$1, TP11.P$1, U4.VDD, U5.5 (VCC); also elsewhere on the board
A7: TP19.P$1
D18: C1.P$2, D41.1 (12), R13.P$1, TP17.P$1
D19: C2.P$2, D42.1 (12), R15.P$1, TP18.P$1
D24: C3.P$2, D43.1 (12), R17.P$1, TP15.P$1
D25: C4.P$2, D44.1 (12), R19.P$1, TP14.P$1
GND: C1.P$1, C2.P$1, C3.P$1, C4.P$1, D41.2 (21), D42.2 (21), D43.2 (21), D44.2 (21), D45.2 (21), J1.3, J1.4, J2.3, J2.4, J3.3, J3.4, J4.3, J4.4, TP12.P$1, U4.GND, U5.2 (GND); also elsewhere on the board
I2C_SCL: TP10.P$1, U5.3 (IO2); also elsewhere on the board
I2C_SDA: TP9.P$1, U5.1 (IO1); also elsewhere on the board
unnamed: J1.1, J1.2, R13.P$2, R14.P$2
unnamed: J2.1, J2.2, R15.P$2, R16.P$2
unnamed: J3.1, J3.2, R17.P$2, R18.P$2
unnamed: J4.1, J4.2, R19.P$2, R20.P$2
PIRSIG: TP16.P$1, U4.OUT

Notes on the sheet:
1.0
Eric Burger UC Berkeley

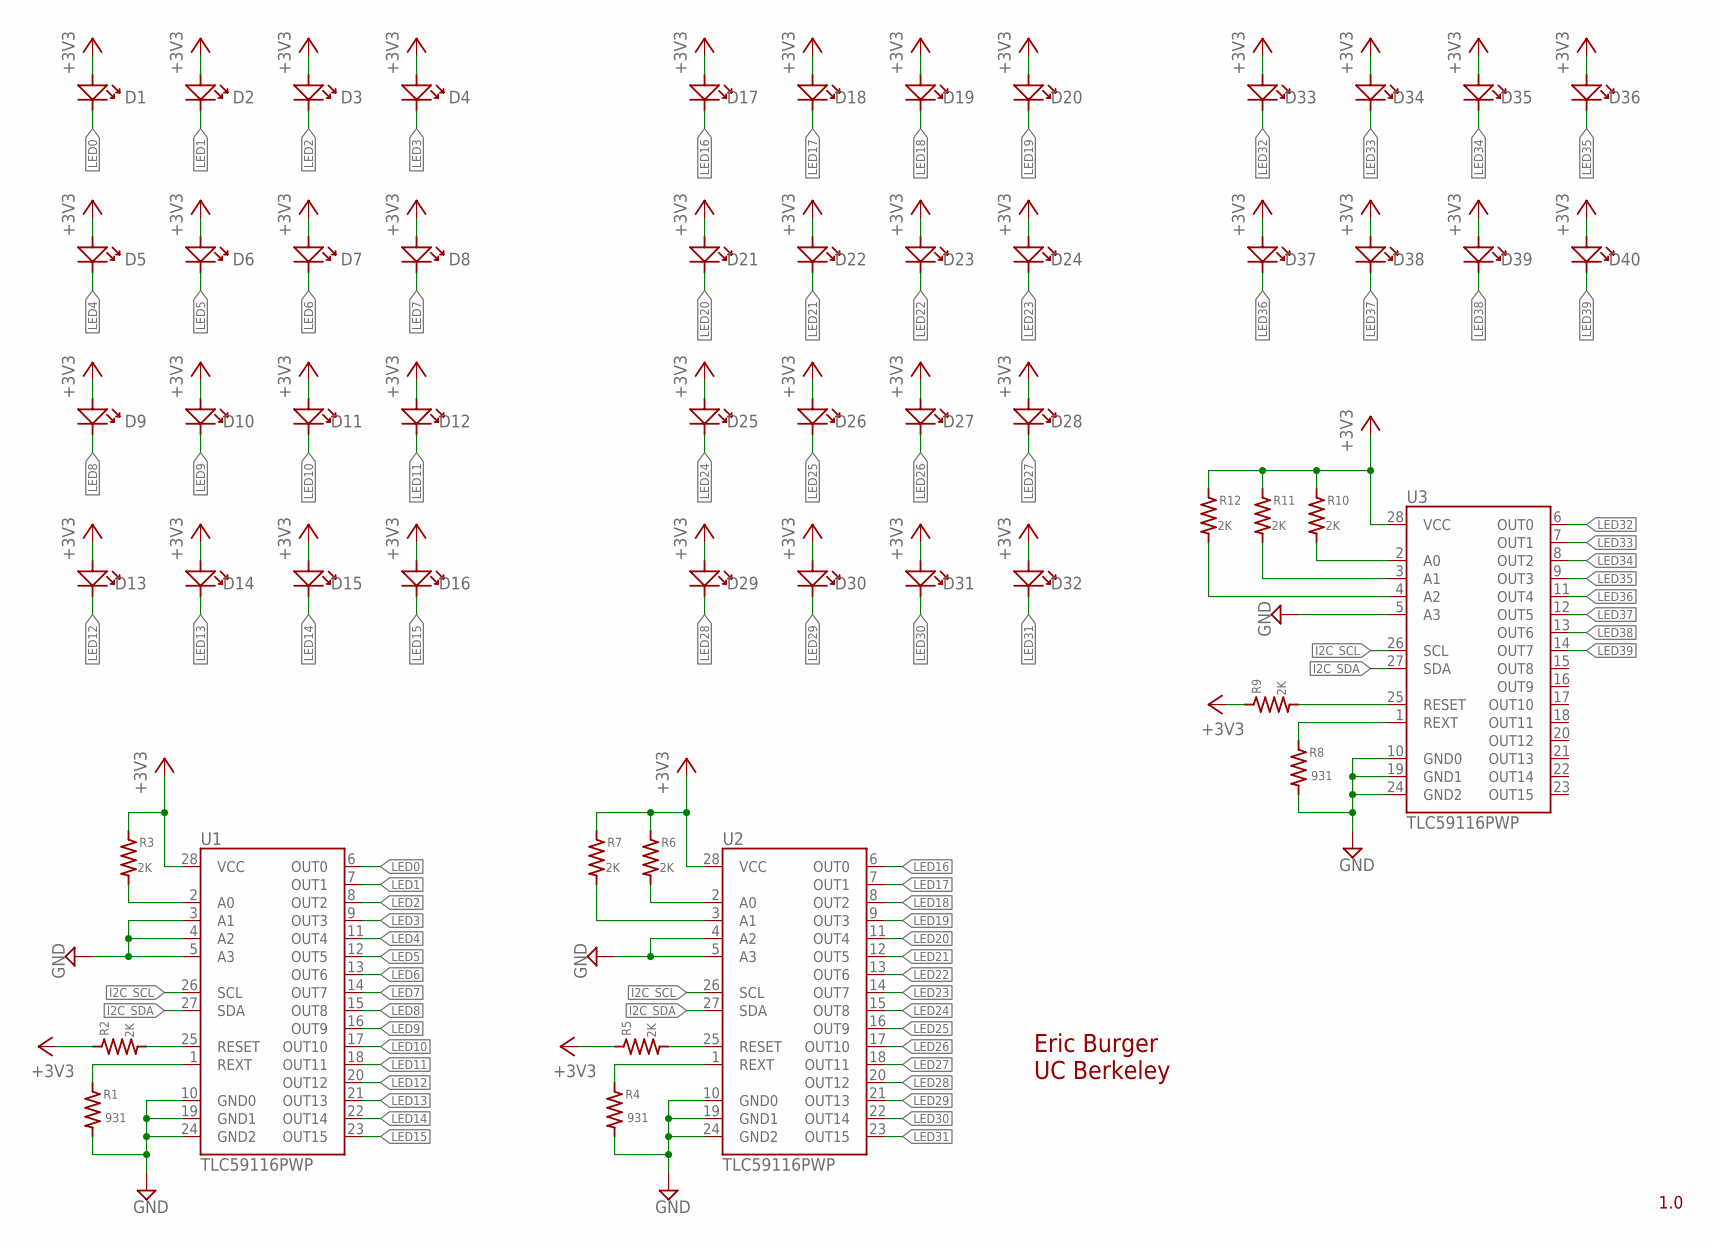
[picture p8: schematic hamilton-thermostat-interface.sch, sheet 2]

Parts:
D1, D2, D3, D4, D5, D6, D7, D8, D9, D10, D11, D12, D13, D14, D15, D16, D17, D18, D19, D20, D21, D22, D23, D24, D25, D26, D27, D28, D29, D30, D31, D32, D33, D34, D35, D36, D37, D38, D39, D40: DNP; LINE_0603
R1, R4, R8: 931; S0402
R2, R3, R5, R6, R7, R9, R10, R11, R12: 2K; S0402
U1, U2, U3: TLC59116PWP; TSSOP28-GROUNDPAD

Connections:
+3V3: D1.P (+), D2.P (+), D3.P (+), D4.P (+), D5.P (+), D6.P (+), D7.P (+), D8.P (+), D9.P (+), D10.P (+), D11.P (+), D12.P (+), D13.P (+), D14.P (+), D15.P (+), D16.P (+), D17.P (+), D18.P (+), D19.P (+), D20.P (+), D21.P (+), D22.P (+), D23.P (+), D24.P (+), D25.P (+), D26.P (+), D27.P (+), D28.P (+), D29.P (+), D30.P (+), D31.P (+), D32.P (+), D33.P (+), D34.P (+), D35.P (+), D36.P (+), D37.P (+), D38.P (+), D39.P (+), D40.P (+), R2.P$2, R3.P$2, R5.P$2, R6.P$2, R7.P$2, R9.P$2, R10.P$2, R11.P$2, R12.P$2, U1.28 (VCC), U2.28 (VCC), U3.28 (VCC); also elsewhere on the board
GND: R1.P$1, R4.P$1, R8.P$1, U1.3 (A1), U1.4 (A2), U1.5 (A3), U1.10 (GND0), U1.19 (GND1), U1.24 (GND2), U2.4 (A2), U2.5 (A3), U2.10 (GND0), U2.19 (GND1), U2.24 (GND2), U3.5 (A3), U3.10 (GND0), U3.19 (GND1), U3.24 (GND2); also elsewhere on the board
I2C_SCL: U1.26 (SCL), U2.26 (SCL), U3.26 (SCL); also elsewhere on the board
I2C_SDA: U1.27 (SDA), U2.27 (SDA), U3.27 (SDA); also elsewhere on the board
LED0: D1.N (-), U1.6 (OUT0)
LED1: D2.N (-), U1.7 (OUT1)
LED2: D3.N (-), U1.8 (OUT2)
LED3: D4.N (-), U1.9 (OUT3)
LED4: D5.N (-), U1.11 (OUT4)
LED5: D6.N (-), U1.12 (OUT5)
LED6: D7.N (-), U1.13 (OUT6)
LED7: D8.N (-), U1.14 (OUT7)
LED8: D9.N (-), U1.15 (OUT8)
LED9: D10.N (-), U1.16 (OUT9)
LED10: D11.N (-), U1.17 (OUT10)
LED11: D12.N (-), U1.18 (OUT11)
LED12: D13.N (-), U1.20 (OUT12)
LED13: D14.N (-), U1.21 (OUT13)
LED14: D15.N (-), U1.22 (OUT14)
LED15: D16.N (-), U1.23 (OUT15)
LED16: D17.N (-), U2.6 (OUT0)
LED17: D18.N (-), U2.7 (OUT1)
LED18: D19.N (-), U2.8 (OUT2)
LED19: D20.N (-), U2.9 (OUT3)
LED20: D21.N (-), U2.11 (OUT4)
LED21: D22.N (-), U2.12 (OUT5)
LED22: D23.N (-), U2.13 (OUT6)
LED23: D24.N (-), U2.14 (OUT7)
LED24: D25.N (-), U2.15 (OUT8)
LED25: D26.N (-), U2.16 (OUT9)
LED26: D27.N (-), U2.17 (OUT10)
LED27: D28.N (-), U2.18 (OUT11)
LED28: D29.N (-), U2.20 (OUT12)
LED29: D30.N (-), U2.21 (OUT13)
LED30: D31.N (-), U2.22 (OUT14)
LED31: D32.N (-), U2.23 (OUT15)
LED32: D33.N (-), U3.6 (OUT0)
LED33: D34.N (-), U3.7 (OUT1)
LED34: D35.N (-), U3.8 (OUT2)
LED35: D36.N (-), U3.9 (OUT3)
LED36: D37.N (-), U3.11 (OUT4)
LED37: D38.N (-), U3.12 (OUT5)
LED38: D39.N (-), U3.13 (OUT6)
LED39: D40.N (-), U3.14 (OUT7)
unnamed: R3.P$1, U1.2 (A0)
unnamed: R6.P$1, U2.2 (A0)
unnamed: R4.P$2, U2.1 (REXT)
unnamed: R5.P$1, U2.25 (RESET)
unnamed: R7.P$1, U2.3 (A1)
unnamed: R1.P$2, U1.1 (REXT)
unnamed: R10.P$1, U3.2 (A0)
unnamed: R2.P$1, U1.25 (RESET)
unnamed: R8.P$2, U3.1 (REXT)
unnamed: R9.P$1, U3.25 (RESET)
unnamed: R11.P$1, U3.3 (A1)
unnamed: R12.P$1, U3.4 (A2)

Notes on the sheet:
1.0
Eric Burger UC Berkeley

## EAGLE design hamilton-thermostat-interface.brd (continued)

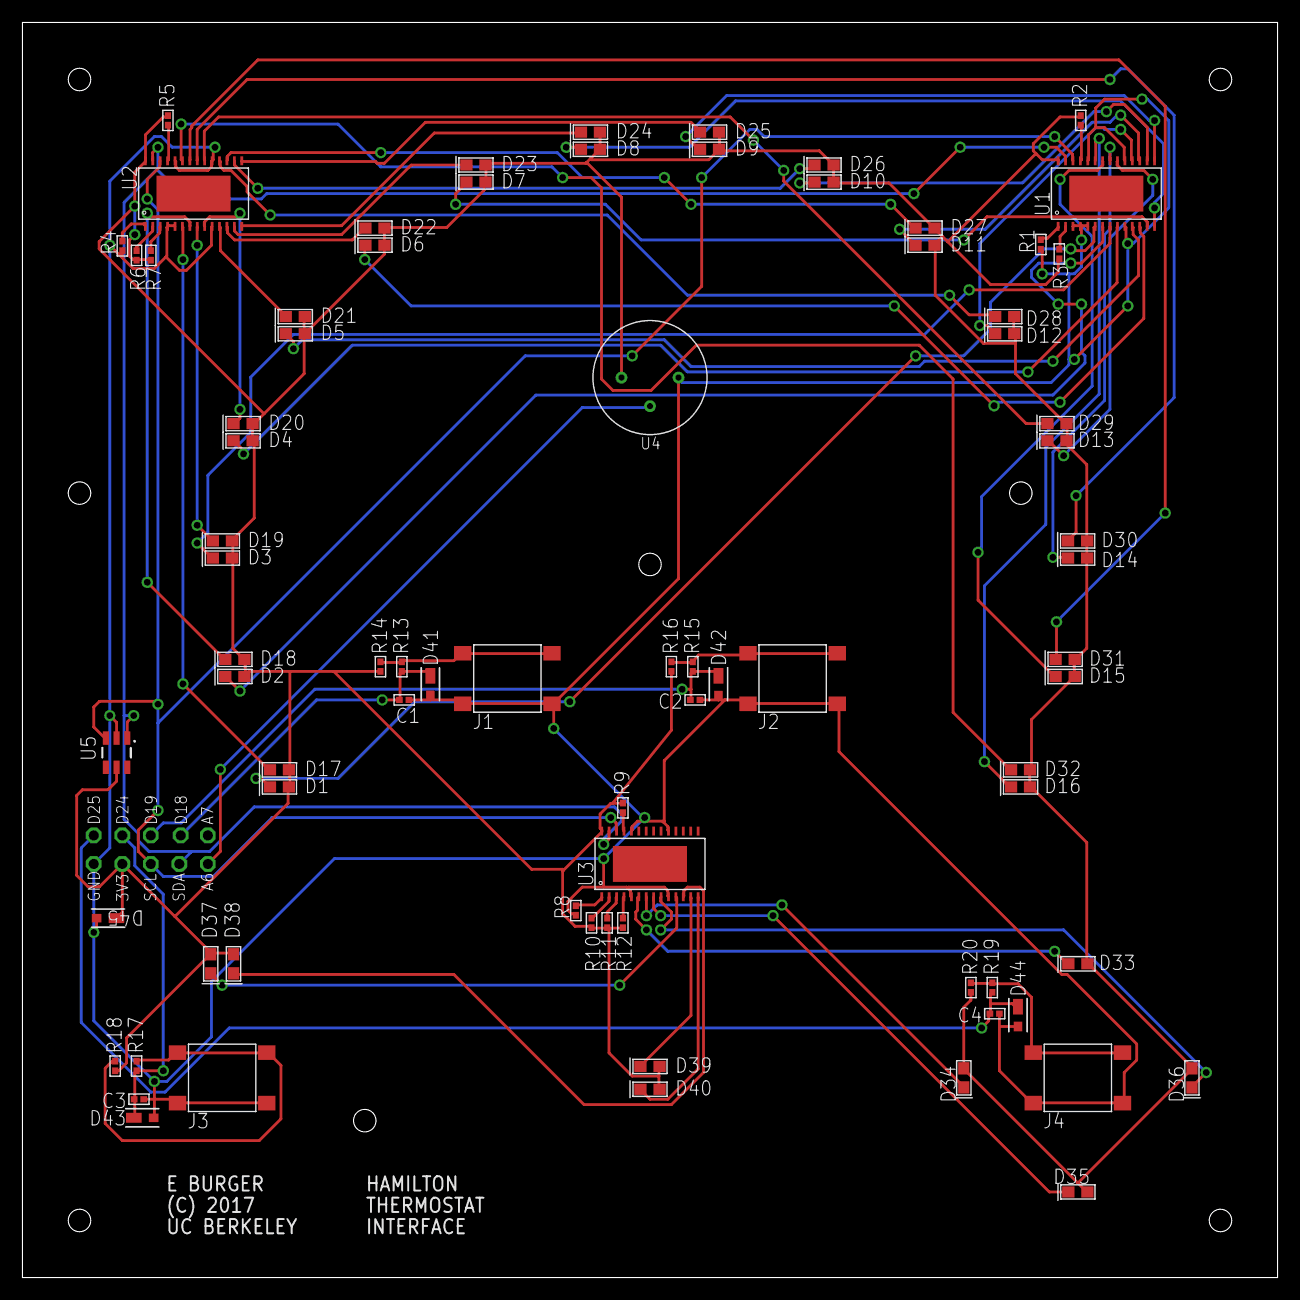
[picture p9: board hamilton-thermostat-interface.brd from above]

Board: 2 copper layers, 111.8 x 111.8 mm, 88 parts (0 on the bottom side), 65 nets.

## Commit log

2017-04-19 Upload Eagle files
    [hamilton-thermostat-interface-BOM.xlsx, hamilton-thermostat-interface.brd, hamilton-thermostat-interface.sch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]
2017-04-28 Add technical details overview
    [hamilton-thermostat-main-BOM.xlsx]
2017-04-29 Move relay jumper location
    [hamilton-thermostat-main.brd]

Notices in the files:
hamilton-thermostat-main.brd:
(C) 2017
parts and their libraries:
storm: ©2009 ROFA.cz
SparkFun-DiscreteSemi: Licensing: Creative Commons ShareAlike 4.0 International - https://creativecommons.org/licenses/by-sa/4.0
